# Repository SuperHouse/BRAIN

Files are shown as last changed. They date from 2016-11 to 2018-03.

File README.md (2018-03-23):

Building Brain Home Automation Controller
==========================================
Copyright 2016-2018 SuperHouse Automation Pty Ltd  www.superhouse.tv  

Home automation controller based on a Raspberry Pi. A Raspberry Pi 3
attaches to this board, which is Arduino-compatible (ATmega328P) and
includes a switch-mode power supply for the Pi, plus 433MHz transmitter
and receiver modules connected to the Arduino. The Arduino can
communicate with the Pi via serial using onboard 3.3V/5V level
shifters, and can send / receive RF messages using the 433MHz modules.

Features:

 * ATmega328P MCU
 * 5V switchmode power supply
 * 433MHz transmitter
 * 433MHz receiver
 * Status LEDs

INSTALLATION
------------
The design is saved as an EAGLE project. EAGLE PCB design software is
available from www.cadsoftusa.com free for non-commercial use. To use
this project download it and place the directory containing these files
into the "eagle" directory on your computer. Then open EAGLE and
navigate to the project.

CREDITS
-------
Designed by Jonathan Oxer jon@oxer.com.au

DISTRIBUTION
------------
The specific terms of distribution of this project are governed by the
license referenced below.

LICENSE
-------
Licensed under the TAPR Open Hardware License (www.tapr.org/OHL).
The "license" folder within this repository also contains a copy of
this license in plain text format.

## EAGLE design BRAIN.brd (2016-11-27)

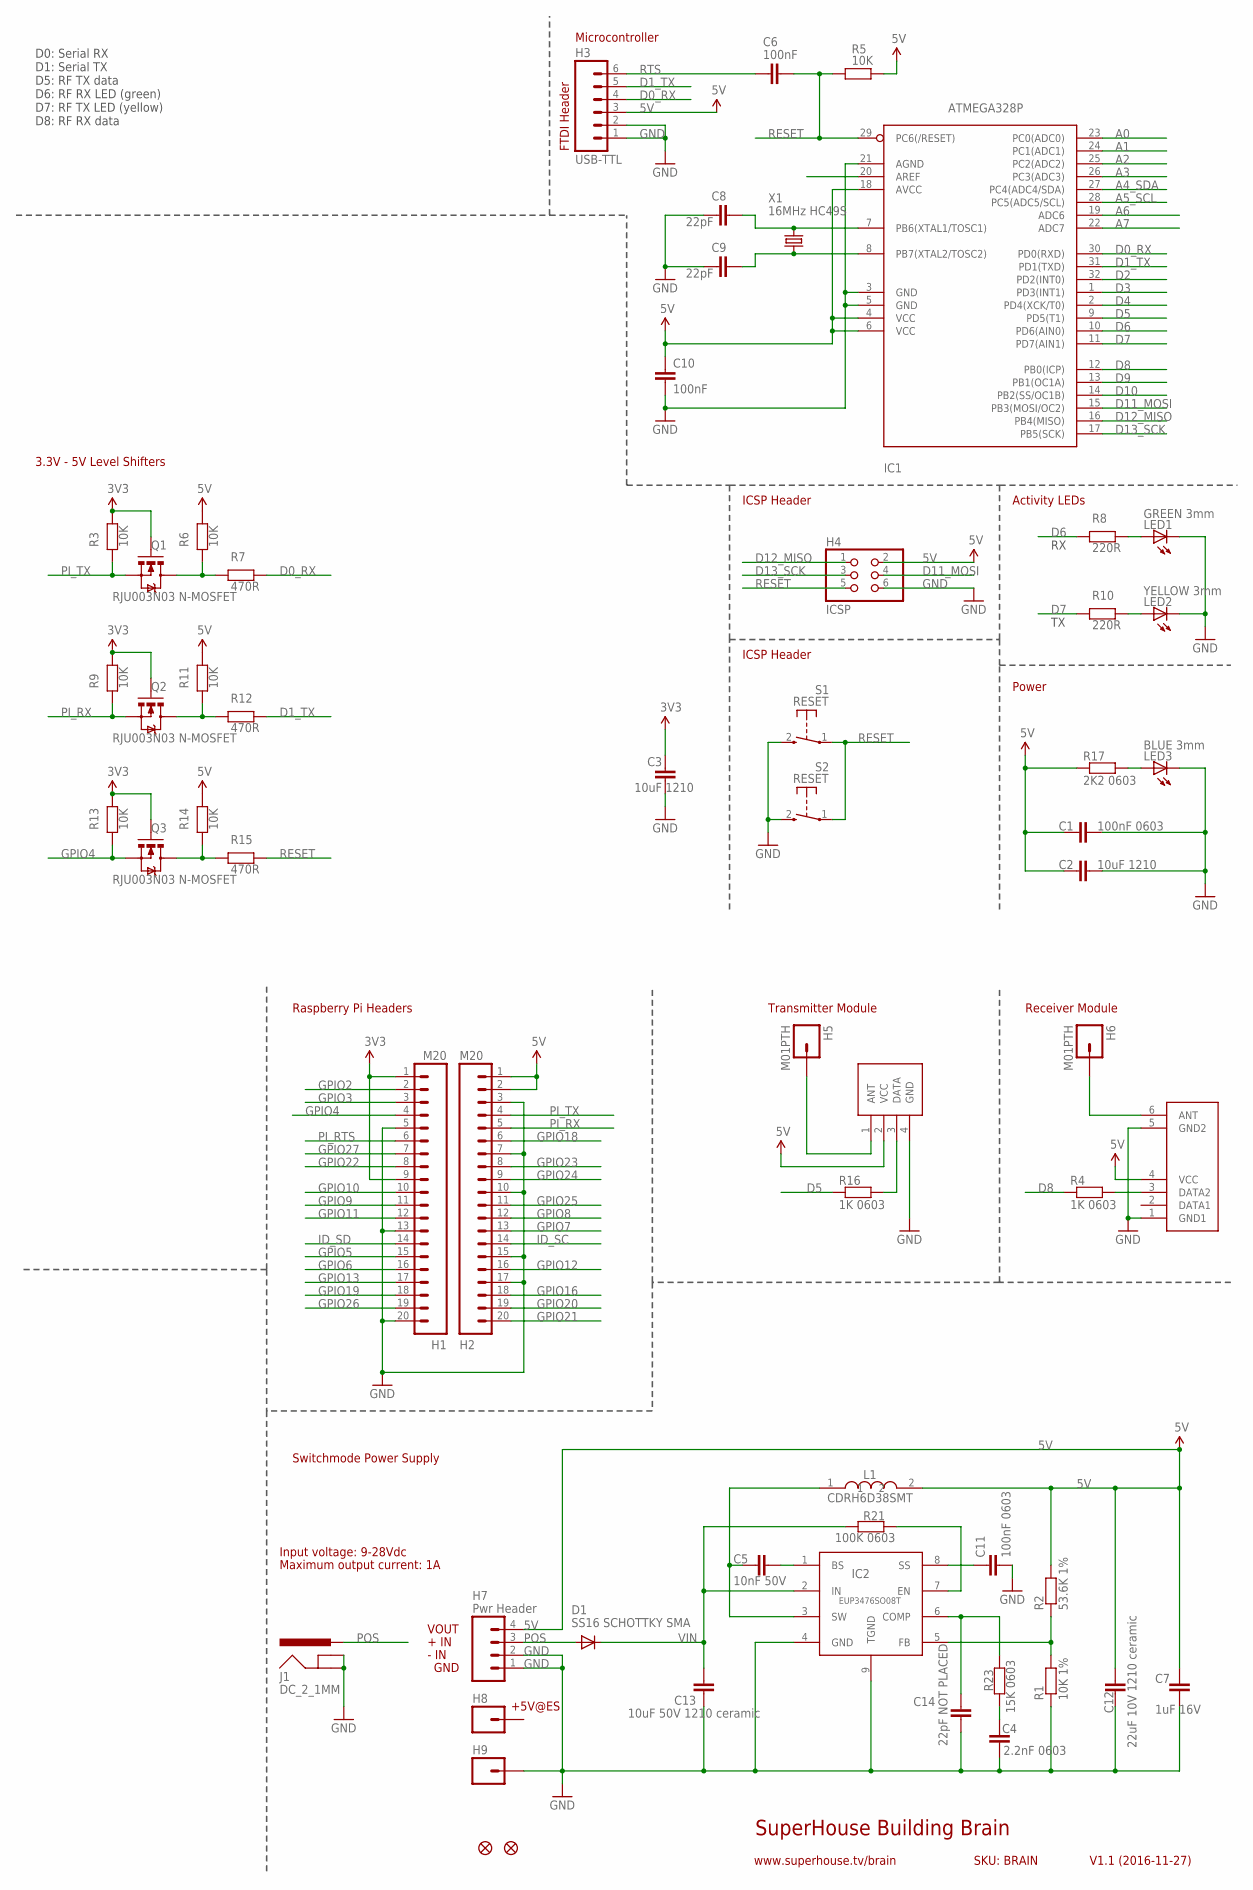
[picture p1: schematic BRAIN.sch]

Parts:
C1, C11: 100nF 0603; 0603
C2, C3: 10uF 1210; C1210
C4: 2.2nF 0603; 0603
C5: 10nF 50V; 0603
C6, C10: 100nF; 0603
C7: 1uF 16V; 0603
C8, C9: 22pF; 0603
C12: 22uF 10V 1210 ceramic; C1210
C13: 10uF 50V 1210 ceramic; C1210
C14: 22pF NOT PLACED; 0603
D1: SS16 SCHOTTKY SMA; SMA-SMB-DIODE
H1, H2: M20; 1X20
H3: USB-TTL; 1X06
H4: ICSP; 2X03
H5, H6, H8, H9: M01PTH; 1X01
H7: Pwr Header; 1X04
IC1: ATMEGA328P; TQFP32-08
IC2: EUP3476SO08T; SO08T
IC3: RXB1; RX-B1-SHORT-FLAT
IC4: TX-C1FLAT; TX-C1-FLAT
J1: DC_2_1MM; POWER_JACK_PTH
L1: CDRH6D38SMT; CDRH
LED1: GREEN 3mm; LED3MM
LED2: YELLOW 3mm; LED3MM
LED3: BLUE 3mm; LED3MM
Q1, Q2, Q3: RJU003N03 N-MOSFET; SOT32-3
R1: 10K 1%; 0603
R2: 53.6K 1%; 0603
R3, R5, R6, R9, R11, R13, R14: 10K; 0603
R4, R16: 1K 0603; 0603
R7, R12, R15: 470R; 0603
R8, R10: 220R; 0603
R17: 2K2 0603; 0603
R21: 100K 0603; 0603
R23: 15K 0603; 0603
S1, S2: RESET; TACTILE_SWITCH_SMD_2PIN_TINY
U$4, U$5: FIDUCIAL1X2.5; FIDUCIAL-1X2.5
X1: 16MHz HC49S; HC49U-V

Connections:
3.3V: C3.1, H1.1, H1.9, Q1.1 (G), Q2.1 (G), Q3.1 (G), R3.1, R9.1, R13.1
5V: C1.1, C2.2, C7.1, C10.1, C12.1, H2.1, H2.2, H3.3, H4.2, H7.4, IC1.4 (VCC), IC1.6 (VCC), IC1.18 (AVCC), IC3.4 (VCC), IC4.2 (VCC), L1.2, R2.2, R5.2, R6.1, R11.1, R14.1, R17.1
A0: IC1.23 (PC0(ADC0))
A1: IC1.24 (PC1(ADC1))
A2: IC1.25 (PC2(ADC2))
A3: IC1.26 (PC3(ADC3))
A4_SDA: IC1.27 (PC4(ADC4/SDA))
A5_SCL: IC1.28 (PC5(ADC5/SCL))
A6: IC1.19 (ADC6)
A7: IC1.22 (ADC7)
AREF: IC1.20 (AREF)
D0_RX: H3.4, IC1.30 (PD0(RXD)), R7.1
D1_TX: H3.5, IC1.31 (PD1(TXD)), R12.1
D2: IC1.32 (PD2(INT0))
D3: IC1.1 (PD3(INT1))
D4: IC1.2 (PD4(XCK/T0))
D5: IC1.9 (PD5(T1)), R16.1
D6: IC1.10 (PD6(AIN0)), R8.2
D7: IC1.11 (PD7(AIN1)), R10.2
D8: IC1.12 (PB0(ICP)), R4.1
D9: IC1.13 (PB1(OC1A))
D10: IC1.14 (PB2(SS/OC1B))
D11_MOSI: H4.4, IC1.15 (PB3(MOSI/OC2))
D12_MISO: H4.1, IC1.16 (PB4(MISO))
D13_SCK: H4.3, IC1.17 (PB5(SCK))
GND: C1.2, C2.1, C3.2, C4.2, C7.2, C8.1, C9.1, C10.2, C11.2, C12.2, C13.2, C14.2, H1.5, H1.13, H1.20, H2.3, H2.7, H2.10, H2.15, H2.17, H3.1, H3.2, H4.6, H7.1, H7.2, H9.1, IC1.3 (GND), IC1.5 (GND), IC1.21 (AGND), IC2.4 (GND), IC2.9 (TGND), IC3.1 (GND1), IC3.5 (GND2), IC4.4 (GND), J1.GND, J1.GNDBREAK, LED1.K (C), LED2.K (C), LED3.K (C), R1.1, S1.2 (S), S2.2 (S)
GPIO2: H1.2
GPIO3: H1.3
GPIO4: H1.4, Q3.2 (S), R13.2
GPIO5: H1.15
GPIO6: H1.16
GPIO7: H2.13
GPIO8: H2.12
GPIO9: H1.11
GPIO10: H1.10
GPIO11: H1.12
GPIO12: H2.16
GPIO13: H1.17
GPIO16: H2.18
GPIO18: H2.6
GPIO19: H1.18
GPIO20: H2.19
GPIO21: H2.20
GPIO22: H1.8
GPIO23: H2.8
GPIO24: H2.9
GPIO25: H2.11
GPIO26: H1.19
GPIO27: H1.7
ID_SC: H2.14
ID_SD: H1.14
unnamed: LED3.A, R17.2
unnamed: Q1.3 (D), R6.2, R7.2
unnamed: H6.1, IC3.6 (ANT)
unnamed: H5.1, IC4.1 (ANT)
unnamed: C8.2, IC1.7 (PB6(XTAL1/TOSC1)), X1.2
unnamed: IC4.3 (DATA), R16.2
unnamed: Q2.3 (D), R11.2, R12.2
unnamed: Q3.3 (D), R14.2, R15.2
unnamed: IC2.7 (EN), R21.1
unnamed: IC2.5 (FB), R1.2, R2.1
unnamed: C14.1, IC2.6 (COMP), R23.2
unnamed: C11.1, IC2.8 (SS)
unnamed: C9.2, IC1.8 (PB7(XTAL2/TOSC2)), X1.1
unnamed: LED1.A, R8.1
unnamed: LED2.A, R10.1
unnamed: C5.2, IC2.1 (BS)
unnamed: C5.1, IC2.3 (SW), L1.1
unnamed: IC3.3 (DATA2), R4.2
unnamed: C4.1, R23.1
PI_RTS: H1.6
PI_RX: H2.5, Q2.2 (S), R9.2
PI_TX: H2.4, Q1.2 (S), R3.2
POS: D1.A, H7.3, J1.PWR
RESET: C6.2, H4.5, IC1.29 (PC6(/RESET)), R5.1, R15.1, S1.1, S2.1
RTS: C6.1, H3.6
VIN: C13.1, D1.C, IC2.2 (IN), R21.2

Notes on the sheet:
SuperHouse Building Brain
SKU: BRAIN
V1.1 (2016-11-27)
Power
Receiver Module
www.superhouse.tv/brain
D0: Serial RX D1: Serial TX D5: RF TX data D6: RF RX LED (green) D7: RF TX LED (yellow) D8: RF RX data
ICSP Header
Microcontroller
FTDI Header
VOUT
+ IN
- IN
GND
Input voltage: 9-28Vdc
Maximum output current: 1A
+5V@ES
Transmitter Module
Raspberry Pi Headers
Switchmode Power Supply
3.3V - 5V Level Shifters
Activity LEDs

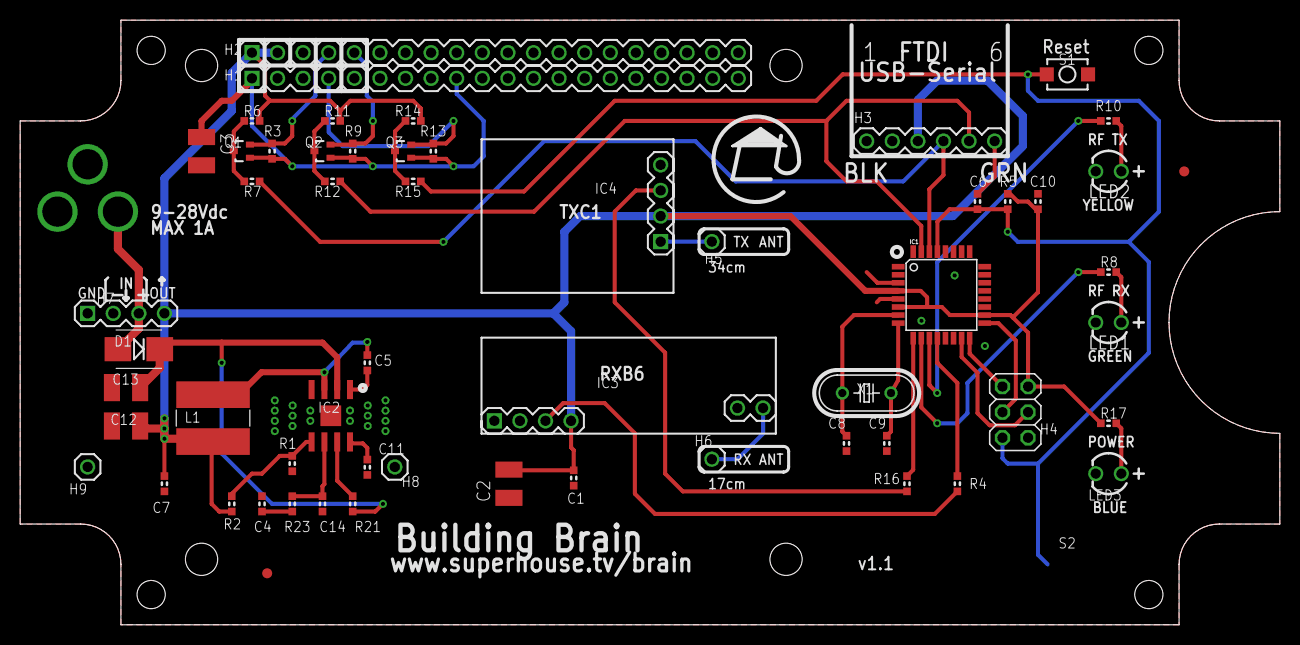
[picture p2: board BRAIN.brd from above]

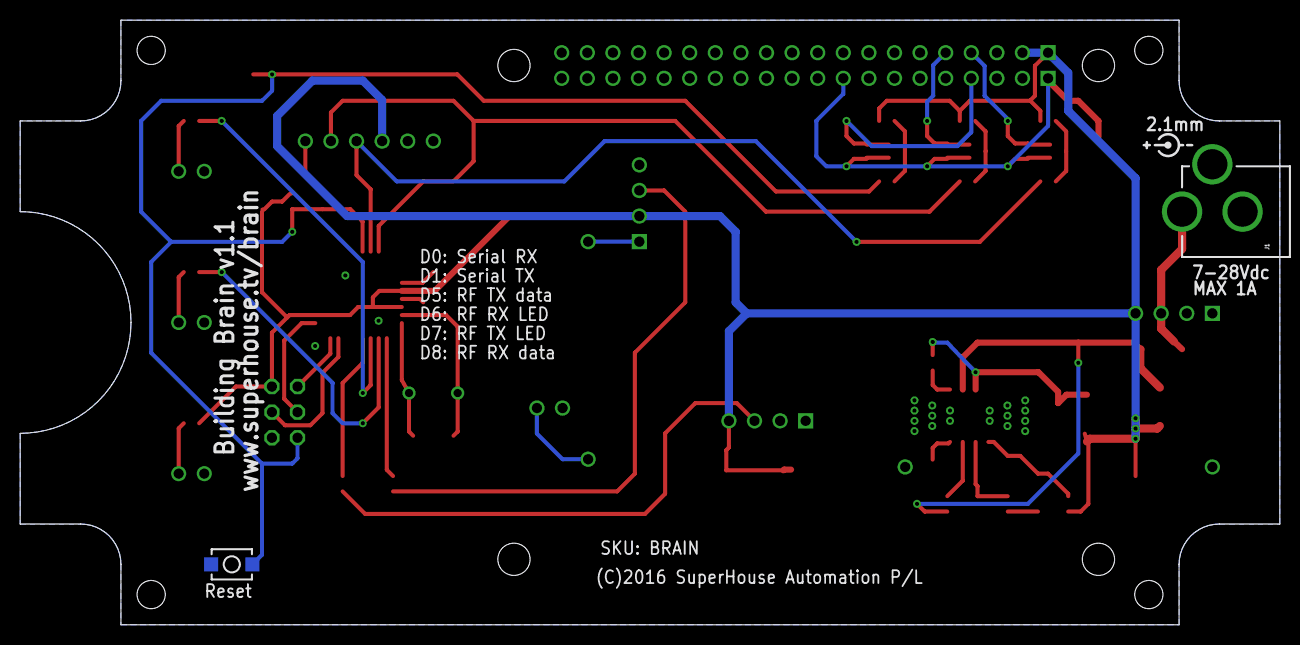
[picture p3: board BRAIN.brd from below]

Board: 2 copper layers, 125.0 x 60.0 mm, 60 parts (2 on the bottom side), 38 nets.

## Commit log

2016-11-27 Initial project import
    [BRAIN.brd, BRAIN.sch]
2016-11-27 Moved Arduino RESET line from RTS to GPIO4 for manual control
    [BRAIN.brd, BRAIN.sch]
2016-11-27 Replaced 0805 footprints with 1210
    [BRAIN.brd, BRAIN.sch]
2016-11-27 Increased Pi holes to 3.2mm and marked Pi headers in use
    [BRAIN.brd]
2016-11-27 Fixed version on silkscreen
    [BRAIN.brd]
2018-03-23 Improved designators
    [BRAIN.sch]
2018-03-23 Renamed project files and added documentation
    [BUILDINGBRAIN.brd, BUILDINGBRAIN.sch]
2018-03-23 Named files back again to match the SKU
    [BRAIN.brd, BRAIN.sch]

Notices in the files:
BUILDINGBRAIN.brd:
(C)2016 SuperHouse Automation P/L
